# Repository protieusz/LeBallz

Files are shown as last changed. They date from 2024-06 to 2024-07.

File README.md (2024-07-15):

# LeBallz
LeBallz, a variant of Le-Chiffre that has a 25mm trackball, 34 or 35 key and optional EC11 encoder.

# Mods
-Pcb dxf was extracted from sporkus's case step file. Pcb uses MX and EC11 footprints only. Pcb is powered by RP2040 Core-A instead of STM32. Pcb done by using EasyEDA.

-Trackball sensor PMW3360 footprint was added to the pcb.

-Top case modded with a large circle cut out hole for a 25mm trackball holder to be friction fit inserted into it so that the holder sits flush with the pcb with sensor underneath it.  Top case have 2 versions mod: One for MX center and another one the EC11 center. Due to financial restrictions, only the MX version will be tested out. Please print at your own risk.

-Bottom case modded with MCU cut out so that the 3mm mcu doesn't rub the bottom case. None haven't been tested yet. 

-QMK code is copied from aki27's bally and modified by changing the matrix to LeBallz. The rest of the core code remains untouched. No support will be given since I only copy paste. Please ask the original author if help is needed.

# Timeline
June 9, 2024: Gerber sent to JLCPC for print and no pcba service was done. I will self pcba on my own with whatever components I have left. Probably no extra pcba will be done. Case files are sent to the local library for 3DP.

Jun 11, 2024: Printed sporkus's case but the trackball holder was a bit tight so I had to use 150 grit sandpaper and sand the circle hole and trackball holder was able to slide in with less friction and adjustable but secure. I have corrected the rectangular case by widening by 3mm on the trackball holder but print at your own risk. I did not do it for the other case. You guys play around trial and error. I haven't printed the corrected 3mm rectangular case yet. Still waiting for the library to print the switch plates first.
JLCPCB progress of pcb is at 71%. Should be ship out by either this week or next week.

Jun 30, 2024: LeBallz build completed.

# Full Production Build Pics



































# Fusion360 & EasyEDA Renders







Screenshot 2024-06-10 at 8 48 10 AM
Screenshot 2024-06-08 at 10 56 44 PM
Screenshot 2024-06-11 at 7 52 50 AM
Screenshot 2024-06-11 at 6 55 36 AM
Screenshot 2024-06-09 at 6 13 11 PM
Screenshot 2024-06-09 at 6 13 38 PM
Screenshot 2024-06-09 at 6 14 18 PM

# Credit

Original Le-Chiffre design by https://github.com/tominabox1/Le-Chiffre-Keyboard?tab=readme-ov-file

Case & PCB files modded from sporkus. https://github.com/sporkus/le_chiffre_keyboard_stm32

# License
Since the pcb dxf outline & case file mod were taken from sporkus's Github, hence the licensing follows his.

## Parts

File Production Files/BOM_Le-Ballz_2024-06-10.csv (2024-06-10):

ID | Name | Designator | Footprint | Quantity | Manufacturer Part | Manufacturer | Supplier | Supplier Part | Price | link
1 | PRTR5V0U2X,215 | D11 | SOT-143_L2.9-W1.3-P1.92-LS2.3-BR | 1 | PRTR5V0U2X,215 | Nexperia(安世) | LCSC | C12333 | 0.097 | https://item.szlcsc.com/280548.html
2 | BSMD0805-020-15V | F1 | F0805 | 1 | BSMD0805-020-15V | BHFUSE(佰宏) | LCSC | C883103 | 0.044 | https://item.szlcsc.com/343298.html
3 | 4.7uF | C17,C19,C20 | C0402 | 3 | CL05A475MP5NRNC | SAMSUNG(三星) | LCSC | C23733 | 0.005 | https://lcsc.com/eda_search?q=C23733&%26type=1&ref=editor
4 | 100nF | C18 | C0402 | 1 | CL05B104KB54PNC | SAMSUNG(三星) | LCSC | C307331 | 0.005 | https://lcsc.com/eda_search?q=C307331&%26type=1&ref=editor
5 | DIODE-SOD123 | D000,D001,D002,D003,D004,D005,D006,D007,D008,D009,D010,D100,D101,D102,D103,D104,D106,D107,D108,D109,D110,D200,D201,D202,D203,D204,D206,D207,D208,D209,D210,D302,D304,D306,D308 | DIODE-SOD123 | 35
6 | NO | ENCB | PIN 1-PIN | 1
7 | 5.1kΩ | R1,R2 | R0402 | 2 | 0402WGF5101TCE | UNI-ROYAL(厚声) | LCSC | C25905 | 0.001 | https://item.szlcsc.com/323315.html
8 | 10kΩ | R10,R12,R13 | R0402 | 3 | 0402WGF1002TCE | UNI-ROYAL(厚声) | LCSC | C25744 | 0.001 | https://lcsc.com/eda_search?q=C25744&%26type=1&ref=editor
9 | 39Ω | R11 | R0402 | 1 | 0402WGJ0390TCE | UNI-ROYAL(厚声) | LCSC | C25164 |  | https://lcsc.com/eda_search?q=C25164&%26type=1&ref=editor
10 | 15kΩ | R14 | R0402 | 1 | 0402WGF1502TCE | UNI-ROYAL(厚声) | LCSC | C25756 | 0.001 | https://lcsc.com/eda_search?q=C25756&%26type=1&ref=editor
11 | RP2040-Core-A | U1 | RP2040-CORE-A | 1
12 | AP2127K-ADJTRG1 | U10 | SOT-23-5_L3.0-W1.7-P0.95-LS2.8-BR | 1 | AP2127K-ADJTRG1 | DIODES(美台) | LCSC | C96343 | 0.073 | https://lcsc.com/eda_search?q=C96343&%26type=1&ref=editor
13 | PMW3360DM-T2QU | U11 | PMW3360DM-T2QU.PACK | 1 | PMW3360DM-T2QU |  |  |  |  | http://www.pixart.com/upload/PMS0058-PMW3360DM-T2QU-NNDS-R1.30-06042016_20160902201411.pdf
14 | TYPE-C-31-M-12 | USBC1 | USB-C_SMD-TYPE-C-31-M-12 | 1 | TYPE-C-31-M-12 | 韩国韩荣 | LCSC | C165948 | 0.167 | https://so.szlcsc.com/global.html?c=&k=C165948
15 | Switch | K000,K001,K002,K003,K004,K005,K006,K007,K008,K009,K010,K100,K101,K102,K103,K104,K106,K107,K108,K109,K110,K200,K201,K202,K203,K204,K206,K207,K208,K209,K210,K302,K304,K306,K308 | CHERRY_MX_100_MILLMAX | 35
16 | PEC11R-4015F-S0024 | E005 | SW-TH_PEC11R-4XXXF-SXXXX | 1 | PEC11R-4015F-S0024 | BOURNS | LCSC | C143789 | 2.421 | https://item.szlcsc.com/155120.html

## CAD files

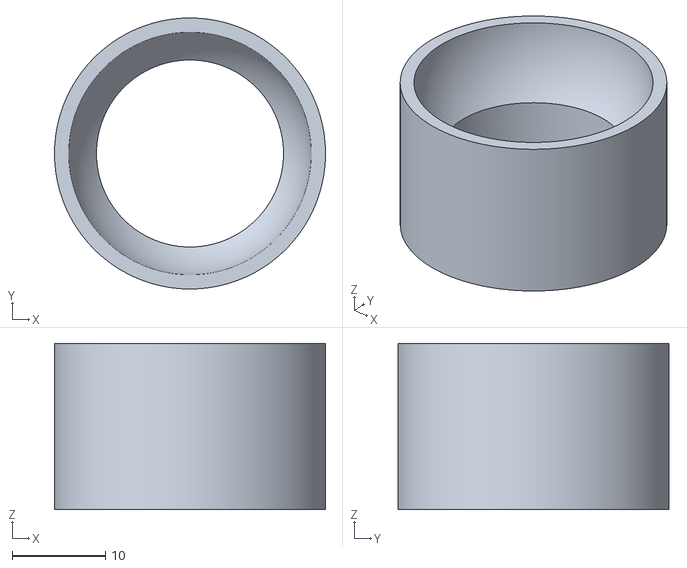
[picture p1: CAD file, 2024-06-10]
STLs/PKTrackball25minicomplete.stl
29.0 x 29.0 x 17.8

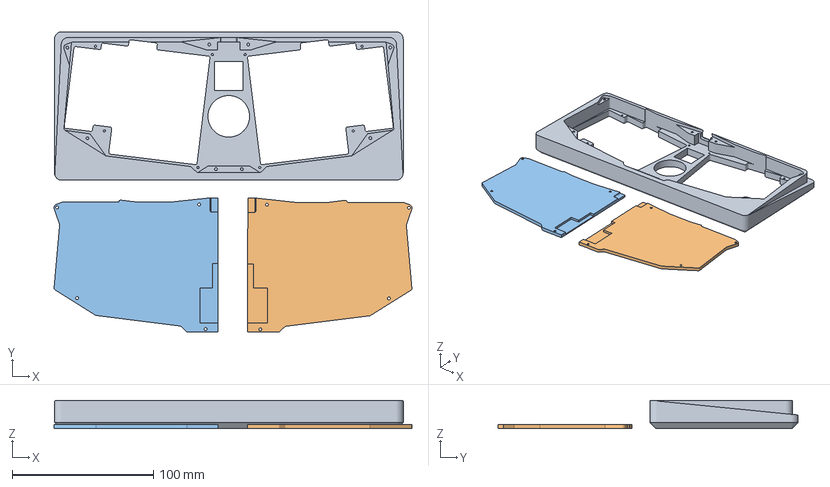
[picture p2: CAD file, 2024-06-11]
RPL/UMS7_LeBallz Rec Top BottomCase MX.3mf
253.0 x 212.3 x 20.1 mm
LeBallz Rec Top Case MX.stl
LeBallz Bottom Right Mcu cutout.stl
LeBallz Bottom Left Mcu cutout.stl

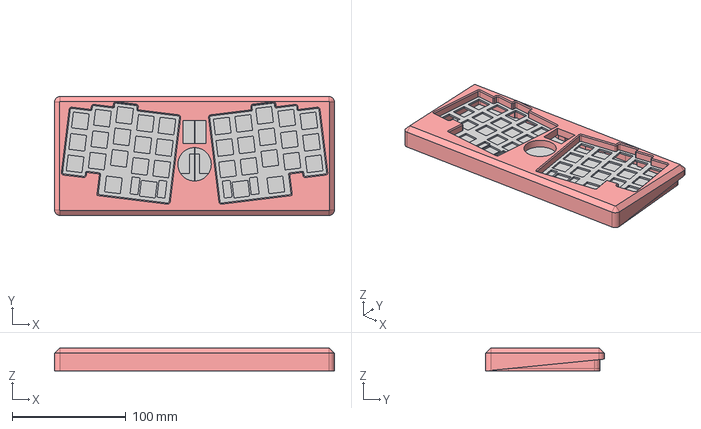
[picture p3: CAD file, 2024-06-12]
STEPs/Original Rectangle Case/LeBallz Rec Case Corrected TB Size.step
246.5 x 104.9 x 20.1 mm
stm32_hotswap_chiffre-3D v3
Le Chiffre Ballz Square v1

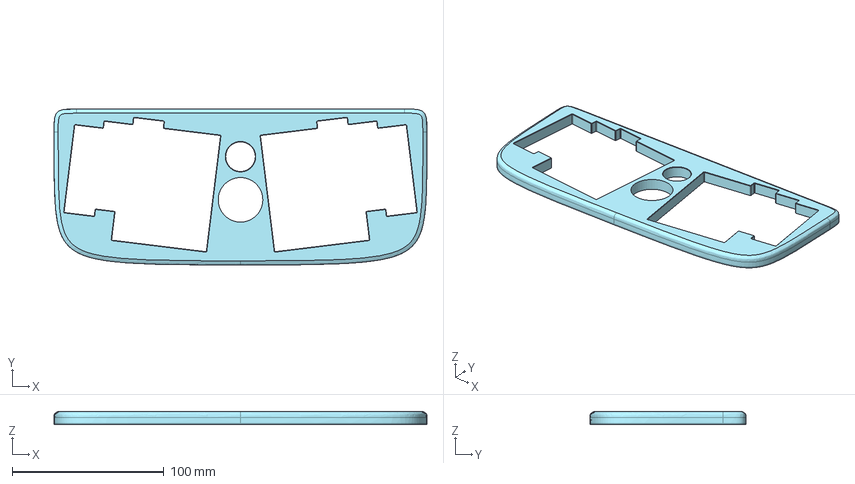
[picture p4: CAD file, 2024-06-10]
STEPs/Sporkus Modded case/LeBallz Top Encoder Hole.step
246.0 x 102.9 x 8.55 mm
stm32_hotswap_chiffre-3D v3
Top Round Hole

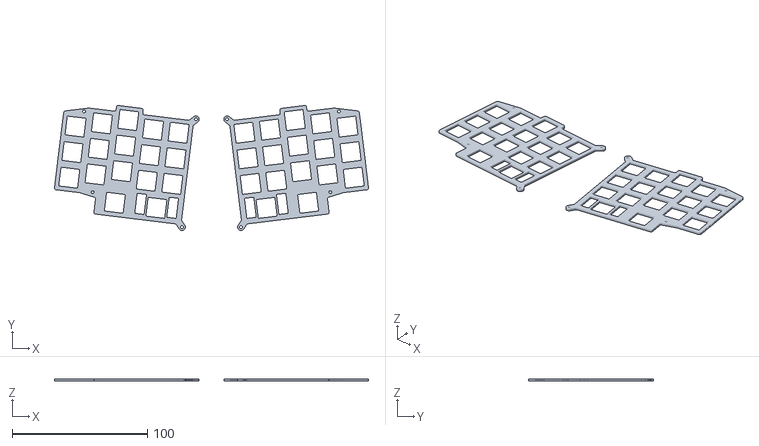
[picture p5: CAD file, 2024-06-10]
STLs/LeBallz Plate.stl
232.2 x 92.5 x 1.60

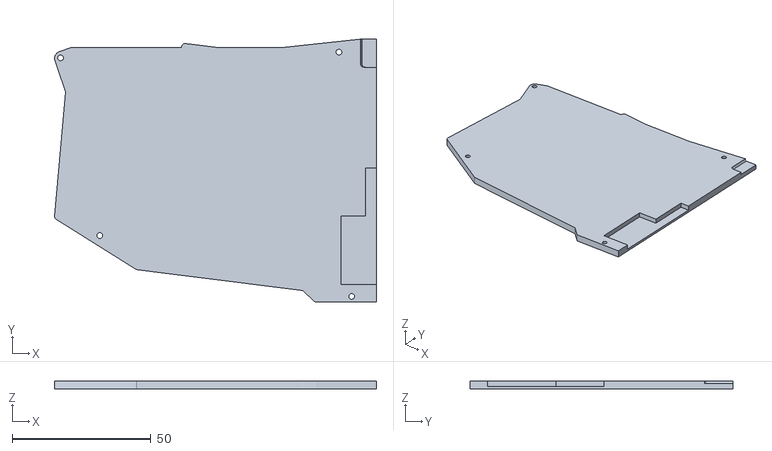
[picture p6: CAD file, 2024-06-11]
STLs/Rectangle Leballz/LeBallz Bottom Left Mcu cutout.stl
116.1 x 94.8 x 3.00

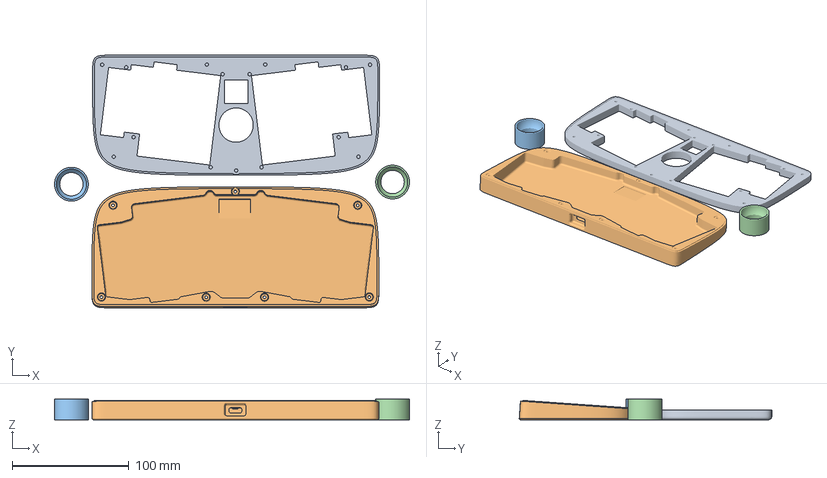
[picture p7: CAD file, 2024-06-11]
RPL/UMS7_LeBallz TopBottomTBHolder.3mf
304.3 x 216.5 x 17.8 mm
LeBallz Top MX Hole.stl
LeBallz Bottom MCU cutout.stl
PKTrackball25minicomplete.stl
PKTrackball25minicomplete.stl(1)

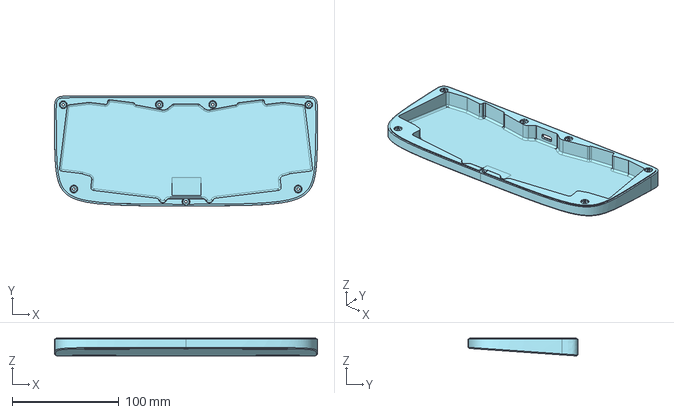
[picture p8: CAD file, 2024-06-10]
STEPs/Sporkus Modded case/LeBallz Bottom MCU cutout.step
246.0 x 102.9 x 16.8 mm
stm32_hotswap_chiffre-3D v3
bottom_case

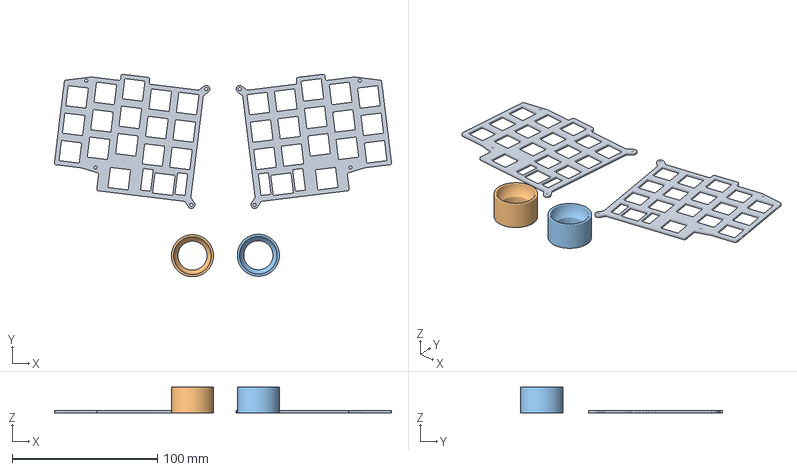
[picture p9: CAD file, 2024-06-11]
RPL/UMS7_LeBallz PlateTBHolder.3mf
232.2 x 139.5 x 17.8 mm
LeBallz Plate.stl
PKTrackball25minicomplete.stl
PKTrackball25minicomplete.stl(1)

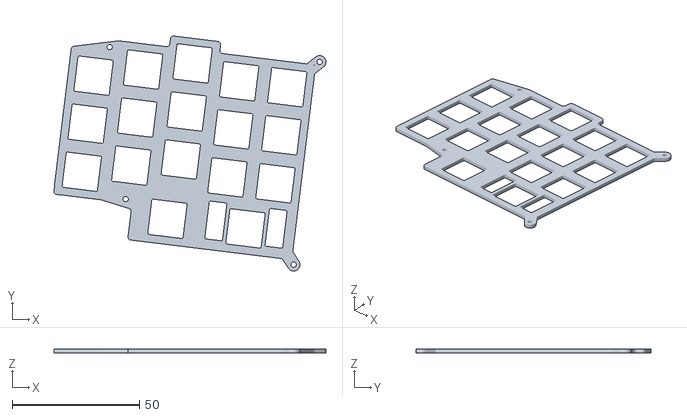
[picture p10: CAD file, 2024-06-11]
STLs/Rectangle Leballz/LeBallz Rec LeftPlate.stl
107.1 x 92.5 x 1.60

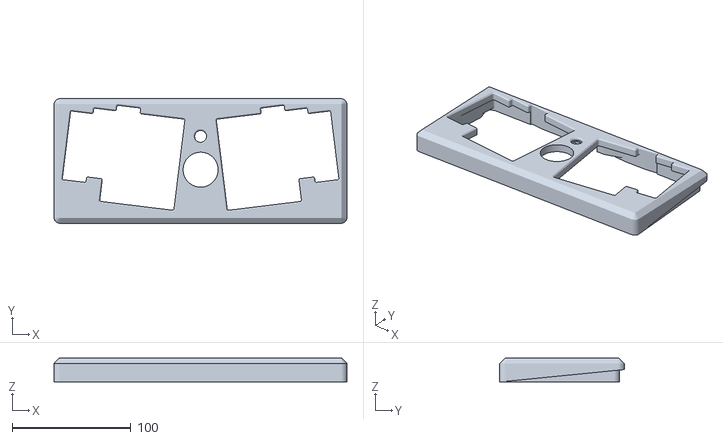
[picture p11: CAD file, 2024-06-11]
STLs/Rectangle Leballz/LeBallz Rec Top Case Encoder.stl
246.5 x 104.9 x 20.1

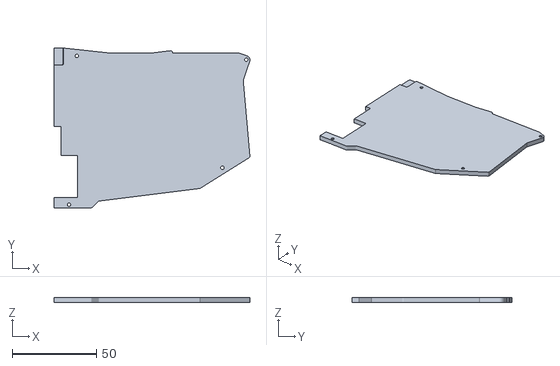
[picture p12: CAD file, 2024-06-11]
STLs/Rectangle Leballz/LeBallz Rec Bottom Left Cutout.stl
116.1 x 94.8 x 3.00

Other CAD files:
STEPs/Original Rectangle Case/LeBallz Rec Case Encoder.step
STLs/LeBallz Top MX Hole.stl
STLs/Rectangle Leballz/LeBallz Bottom Right Mcu cutout.stl
STEPs/Original Rectangle Case/LeBallz Rec Case MX.step
STEPs/Sporkus Modded case/LeBallz Center Keycap Hole.step
STLs/LeBallz Bottom MCU cutout.stl
STLs/Rectangle Leballz/LeBallz Rec Bottom Right Cutout.stl
STLs/Rectangle Leballz/LeBallz Rec RightPlate.stl
STLs/Rectangle Leballz/LeBallz Rec Top Case MX.stl

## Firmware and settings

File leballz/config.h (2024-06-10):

// Copyright 2024 ProtieusKeebs
// SPDX-License-Identifier: GPL-2.0-or-later

#pragma once

//#define VIAL_KEYBOARD_UID {0xC4, 0x18, 0xCC, 0x6D, 0x1C, 0x16, 0x5B, 0x8D}
//#define VIAL_UNLOCK_COMBO_ROWS {0, 0}
//#define VIAL_UNLOCK_COMBO_COLS {1, 11}

/* VIA */
//#define DYNAMIC_KEYMAP_LAYER_COUNT 8


/* key matrix size */
//#define MATRIX_COLS 13
//#define MATRIX_ROWS 4


/* tapping term */
// #define TAPPING_FORCE_HOLD
//#define TAPPING_TERM 200
// #define IGNORE_MOD_TAP_INTERRUPT

#define RP2040_BOOTLOADER_DOUBLE_TAP_RESET // Activates the double-tap behavior
#define RP2040_BOOTLOADER_DOUBLE_TAP_RESET_TIMEOUT 200U // Timeout window in ms in which the double tap can occur.

#ifdef COMBO_ENABLE
#    define COMBO_COUNT 3
#    define COMBO_TERM 200
#endif

/* Encoder */
//#define ENCODERS_PAD_A { GP11 }
//#define ENCODERS_PAD_B { GP12 }
//#define ENCODER_RESOLUTION 4

/* Matrix*/
//#define MATRIX_COL_PINS { GP25, GP24, GP23, GP22, GP21, GP26, GP27, GP20, GP19, GP18, GP17, GP16, GP13 }
//#define MATRIX_ROW_PINS { GP28, GP10, GP14, GP15 }

/* COL2ROW, ROW2COL */
//#define DIODE_DIRECTION COL2ROW


/* Set 0 if debouncing isn't needed */
//#define DEBOUNCE 5


/* Mechanical locking support. Use KC_LCAP, KC_LNUM or KC_LSCR instead in keymap (Very Important for Scroll Lock!!!) */
#undef LOCKING_SUPPORT_ENABLE
/* Locking resynchronize hack */
#undef LOCKING_RESYNC_ENABLE


/* Trackball */

#ifdef POINTING_DEVICE_ENABLE

//#    undef RP_SPI_USE_SPI0
//#    define RP_SPI_USE_SPI0 TRUE
//#    undef RP_SPI_USE_SPI1
//#    define RP_SPI_USE_SPI1 FALSE
#    define SPI_DRIVER SPID1

//#    define SPI_SCK_PIN GP22 //6
//#    define SPI_MISO_PIN GP24 //4
//#    define SPI_MOSI_PIN GP23 //7
#    define SPI_SCK_PIN GP14
#    define SPI_MISO_PIN GP12
#    define SPI_MOSI_PIN GP15

#endif


#ifndef PMW33XX_CS_PIN
#    define PMW33XX_CS_PIN GP13
#endif
#define POINTING_DEVICE_INVERT_X
#define POINTING_DEVICE_INVERT_Y
//#define ROTATIONAL_TRANSFORM_ANGLE 90
#define POINTING_DEVICE_ROTATION_180

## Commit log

2024-06-10 Case STLs
    [LeBallz Bottom MCU cutout.stl, LeBallz Plate.stl, LeBallz Top MX Hole.stl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]
2024-06-10 Step files
    [LeBallz Bottom MCU cutout.step, LeBallz Center Keycap Hole.step, LeBallz Top Encoder Hole.step]
2024-06-10 Only BOM & Components placement for now.
    [BOM_Le-Ballz_2024-06-10.csv, PickAndPlace_PCB_Le-Ballz_2024-06-10.csv]
2024-06-11 Case Files
    [LeBallz Bottom MCU cutout.step, LeBallz Bottom MCU cutout.stl, LeBallz Center Keycap Hole.step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]
2024-06-11 Correct the bottom mcu cut out
    [LeBallz Bottom Left Mcu cutout.stl, LeBallz Bottom Right Mcu cutout.stl]
2024-06-11 Updated the bottom plate mcu cut out
    [UMS7_LeBallz Rec Top BottomCase MX.3mf]
2024-06-12 Widen the trackball hole to 3mm
    [LeBallz Rec Case Corrected TB Size.step]
